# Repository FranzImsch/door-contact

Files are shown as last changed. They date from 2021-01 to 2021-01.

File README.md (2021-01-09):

# "Dr. Sens" Door Contact

## Features
nRF52832-based magnetic door or window contact. It features a <strong>reed switch</strong> that triggers an interrupt pin of the MCU which then sends a message via <strong>Nordic's ESB protocol</strong> to a gateway. The device is powered by a <strong>CR1632 battery cell</strong>.

The board also serves as breakout for i²c and SPI (pin assignment of nrf52-DK) and a pushbutton that is in parallel to the reed switch is populated. This is for development and makes it possible that the board can <strong>be used as a dashbutton</strong>, for example, as well. There is a TX/RX header as well for easy debugging.

## Software
The software was written using the Arduino-Framework. For communication, the [MySensors Library](https://github.com/mysensors) is being used. The MCU goes to sleep until the interrupt is being triggered. After that, it sends a message (along with the battery charge status) to a gateway. When no ACK is received, the message is resend a set number of times.

## Renderings
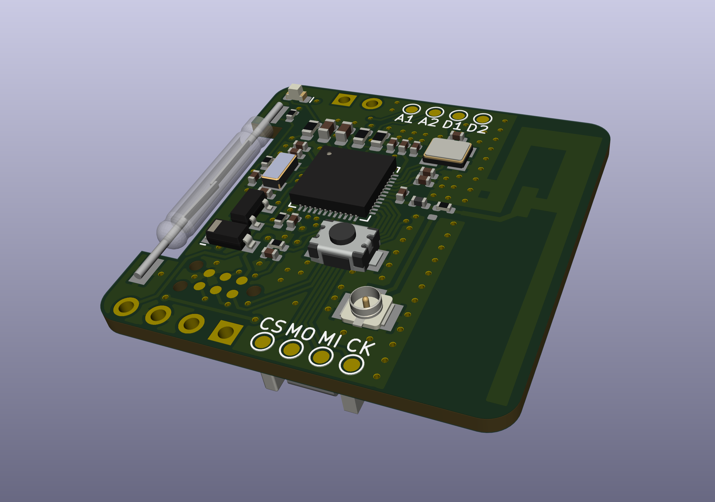
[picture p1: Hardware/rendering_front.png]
Rendering

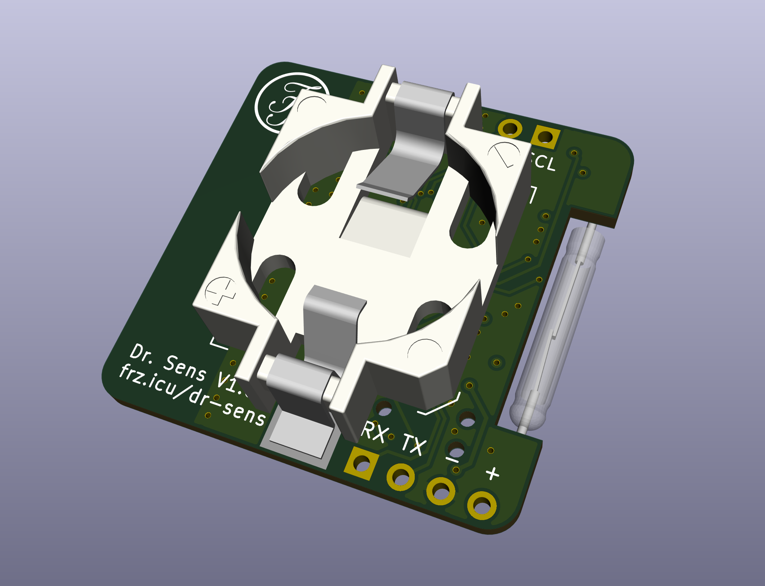
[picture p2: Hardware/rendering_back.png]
Rendering


## Disclaimer
The board is still in development and I do not guarantee any functionality whatsoever. I do not recommend that you use this device to protect your property.

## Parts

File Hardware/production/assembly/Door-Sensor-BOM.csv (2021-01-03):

Comment | Designator | Footprint | LCSC
Antenna_Shield | AE1 | RF_Antenna:Texas_SWRR034C_2.4GHz_Right
Battery_Cell | BT1 | Battery:BatteryHolder_MYOUNG_BS-16-B4AK003
10nF | C1 | Capacitor_SMD:C_0402_1005Metric | C15195
100nF | C4,C5,C10,C15 | Capacitor_SMD:C_0402_1005Metric | C1525
0.8pF | C11 | Capacitor_SMD:C_0402_1005Metric
16pF | C2,C3,C12,C13 | Capacitor_SMD:C_0402_1005Metric | C1548
4.7µF | C6 | Capacitor_SMD:C_0603_1608Metric | C19666
1.0µF | C7 | Capacitor_SMD:C_0603_1608Metric | C15849
100pF | C8 | Capacitor_SMD:C_0402_1005Metric | C1546
DNP | C9,C14 | Capacitor_SMD:C_0402_1005Metric
B5819W | D1 | Diode_SMD:D_SOD-123 | C8598
LED PINK | D2 | LED_SMD:LED_0603_1608Metric
I2C-Conn | J1 | Connector_PinSocket_2.54mm:PinSocket_1x02_P2.54mm_Vertical
PWR-SERIAL-CONN | J2 | Connector_PinHeader_2.54mm:PinHeader_1x04_P2.54mm_Vertical
TC2030 | J3 | Connector:Tag-Connect_TC2030-IDC-NL_2x03_P1.27mm_Vertical
U.FL | J5 | Connector_Coaxial:U.FL_Hirose_U.FL-R-SMT-1_Vertical
3.9nH | L1 | Inductor_SMD:L_0402_1005Metric | C14033
AO3401A | Q1 | Package_TO_SOT_SMD:SOT-23 | C15127
10kΩ | R1 | Resistor_SMD:R_0402_1005Metric | C25744
100kΩ | R2 | Resistor_SMD:R_0402_1005Metric | C25741
4.7MΩ | R3 | Resistor_SMD:R_0603_1608Metric | C23163
10MΩ | R4 | Resistor_SMD:R_0603_1608Metric | C7250
1kΩ | R5 | Resistor_SMD:R_0603_1608Metric | C21190
0Ω | R6 | Resistor_SMD:R_0402_1005Metric | C17168
DNP | R7 | Resistor_SMD:R_0402_1005Metric
1MΩ | R8 | Resistor_SMD:R_0402_1005Metric | C26083
1kΩ | R9 | Resistor_SMD:R_0402_1005Metric | C11702
SW_Reed | SW1 | Button_Switch_SMD:SW_SPST_REED_14.2mm
SW_SPST | SW2 | Button_Switch_SMD:SW_DIP_SPSTx01_Push_TSA343G00-250J2
A1 | TP1 | TestPoint:TestPoint_Pad_D1.0mm
D1 | TP2 | TestPoint:TestPoint_Pad_D1.0mm
D2 | TP3 | TestPoint:TestPoint_Pad_D1.0mm
CS | TP4 | TestPoint:TestPoint_Pad_D1.0mm
MOSI | TP5 | TestPoint:TestPoint_Pad_D1.0mm
MISO | TP6 | TestPoint:TestPoint_Pad_D1.0mm
A2 | TP7 | TestPoint:TestPoint_Pad_D1.0mm
SCK | TP8 | TestPoint:TestPoint_Pad_D1.0mm
nRF52832-QFxx | U1 | Package_DFN_QFN:QFN-48-1EP_6x6mm_P0.4mm_EP4.6x4.6mm | C77540
32.768kHz | Y1 | Crystal:Crystal_SMD_3215-2Pin_3.2x1.5mm | C32346
32MHz | Y2 | Crystal:Crystal_SMD_3225-4Pin_3.2x2.5mm | C9009

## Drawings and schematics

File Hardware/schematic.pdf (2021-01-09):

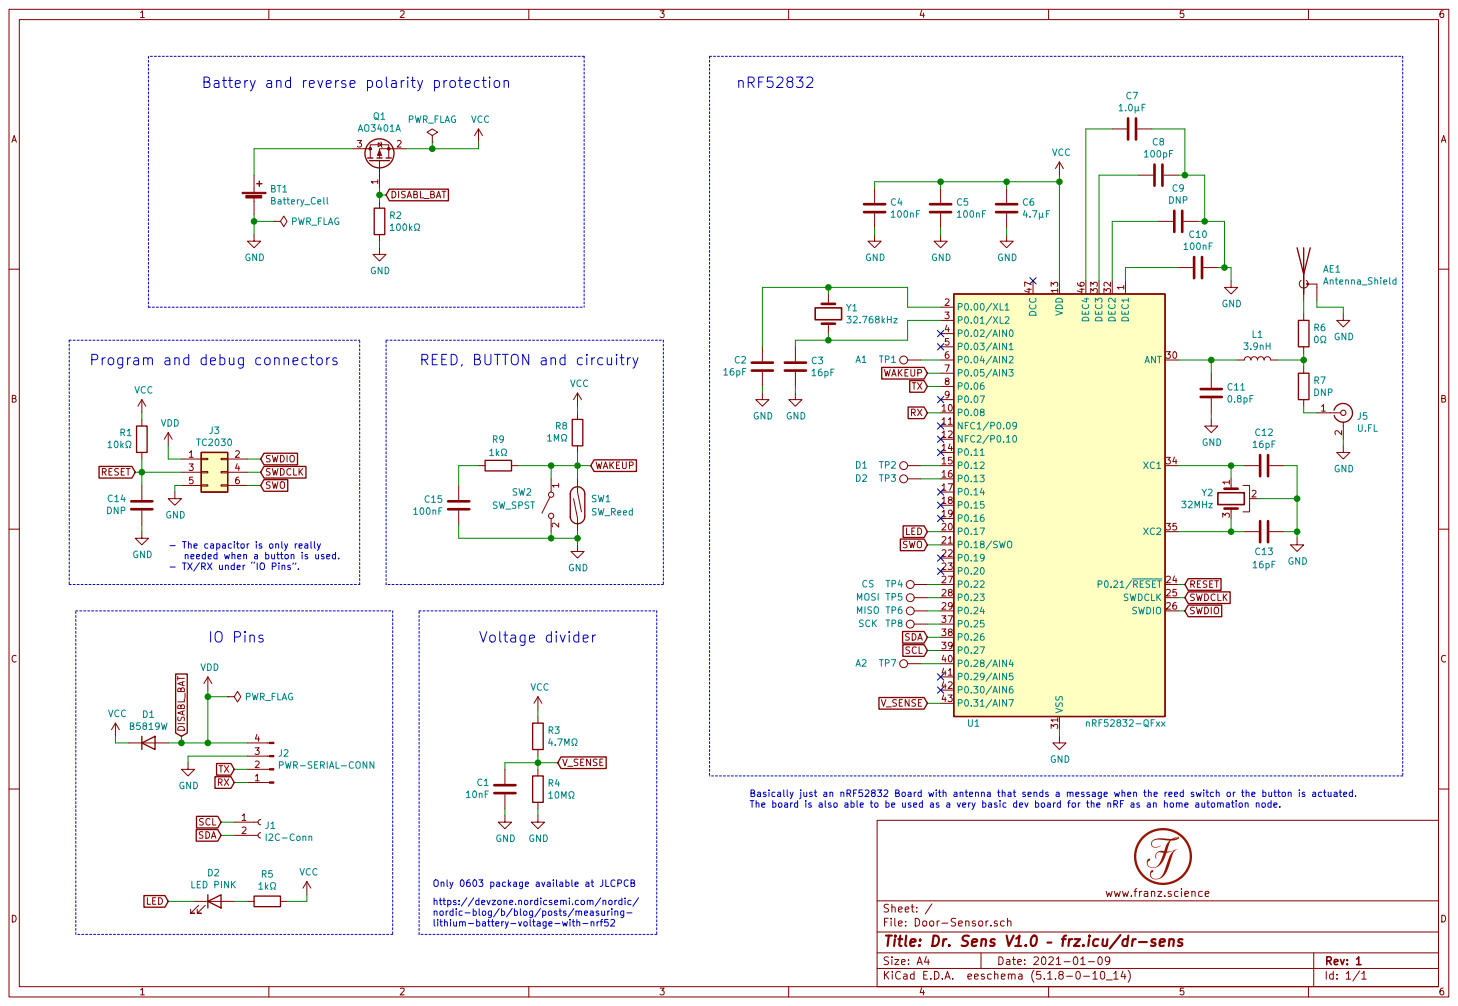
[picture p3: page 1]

1 P0.08 10 NFC1/P0.09 11 NFC2/P0.10 12 VDD 13 P0.11 14 P0.12 15 P0.13 16 P0.14 17 P0.15 18 P0.16 19 P0.00/XL1 2 P0.17 20 P0.18/SWO 21 P0.19 22 P0.20 23 P0.21/RESET 24 SWDCLK 25 SWDIO 26 P0.22 27 P0.23 28 P0.24 29 P0.01/XL2 3 ANT 30 VSS 31 DEC2 32 DEC3 33 XC1 34 XC2 35 P0.25 37 P0.26 38 P0.27 39 P0.02/AIN0 4 P0.28/AIN4 40 P0.29/AIN5 41 P0.30/AIN6 42 P0.31/AIN7 43 DEC4 46 DCC 47 P0.03/AIN1 5 P0.04/AIN2 6 P0.05/AIN3 7 P0.06 8 P0.07 9 U1 nRF52832-QFxx

0 GND GND GND GND

Program and debug connectors

REED, BUTTON and circuitry

- The capacitor is only really

Basically just an nRF52832 Board with antenna that sends a message when the reed switch or the button is actuated.
The board is also able to be used as a very basic dev board for the nRF as an home automation node.

Only 0603 package available at JLCPCB
https://devzone.nordicsemi.com/nordic/
nordic-blog/b/blog/posts/measuring-
lithium-battery-voltage-with-nrf52

Id: 1/1 Title: Dr. Sens V1.0 frz.icu/dr-sens

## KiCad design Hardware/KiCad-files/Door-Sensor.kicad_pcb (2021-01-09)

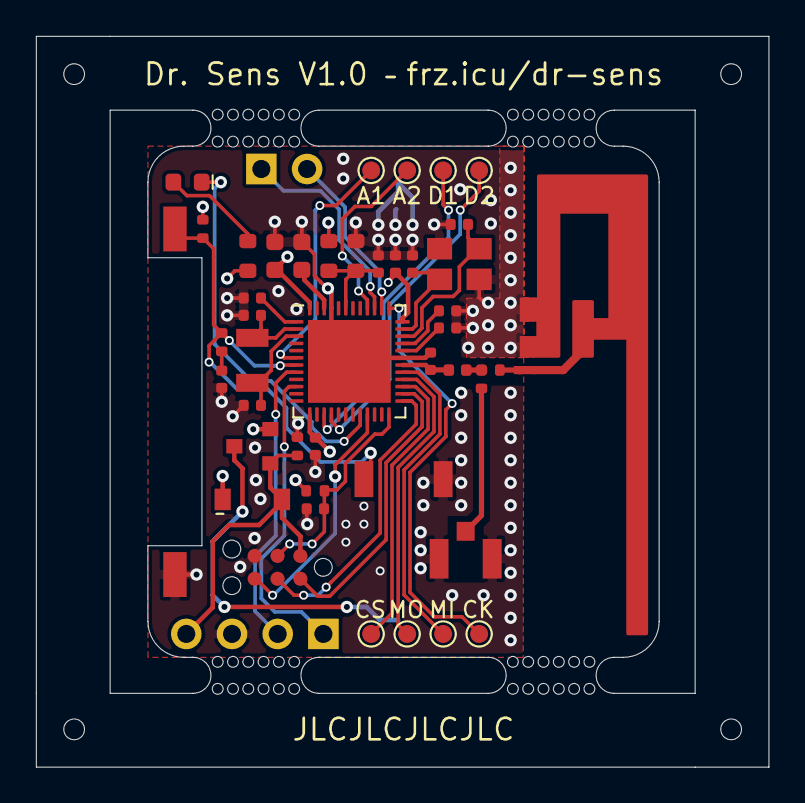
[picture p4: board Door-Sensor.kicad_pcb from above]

Board: 4 copper layers, 40.7 x 40.6 mm, 51 parts (1 on the bottom side), 37 nets.

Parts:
AE1: Antenna_Shield; Texas_SWRR034C_2.4GHz_Right
BT1: Battery_Cell; BatteryHolder_MYOUNG_BS-16-B4AK003
C1: 10nF; C_0402_1005Metric
C2, C3, C12, C13: 16pF; C_0402_1005Metric
C4, C5, C10, C15: 100nF; C_0402_1005Metric
C6: 4.7µF; C_0603_1608Metric
C7: 1.0µF; C_0603_1608Metric
C8: 100pF; C_0402_1005Metric
C9, C14: DNP; C_0402_1005Metric
C11: 0.8pF; C_0402_1005Metric
D1: D; D_SOD-123
D2: LED PINK; LED_0603_1608Metric
J1: I2C-Conn; PinSocket_1x02_P2.54mm_Vertical
J2: PWR-SERIAL-CONN; PinHeader_1x04_P2.54mm_Vertical
J3: TC2030; Tag-Connect_TC2030-IDC-NL_2x03_P1.27mm_Vertical
J5: U.FL; U.FL_Hirose_U.FL-R-SMT-1_Vertical
L1: 3.9nH; L_0402_1005Metric
Q1: AO3401A; SOT-23
R1: 10kΩ; R_0402_1005Metric
R2: 100kΩ; R_0402_1005Metric
R3: 4.7MΩ; R_0603_1608Metric
R4: 10MΩ; R_0603_1608Metric
R5: 1kΩ; R_0603_1608Metric
R6: 0Ω; R_0402_1005Metric
R7: DNP; R_0402_1005Metric
R8: 1MΩ; R_0402_1005Metric
R9: 1kΩ; R_0402_1005Metric
SW1: SW_Reed; SW_SPST_REED_14.2mm
SW2: SW_SPST; SW_DIP_SPSTx01_Push_TSA343G00-250J2
TP1: A1; TestPoint_Pad_D1.0mm
TP2: D1; TestPoint_Pad_D1.0mm
TP3: D2; TestPoint_Pad_D1.0mm
TP4: CS; TestPoint_Pad_D1.0mm
TP5: MOSI; TestPoint_Pad_D1.0mm
TP6: MISO; TestPoint_Pad_D1.0mm
TP7: A2; TestPoint_Pad_D1.0mm
TP8: SCK; TestPoint_Pad_D1.0mm
U1: nRF52832-QFxx; QFN-48-1EP_6x6mm_P0.4mm_EP4.6x4.6mm
Y1: 32.768kHz; Crystal_SMD_3215-2Pin_3.2x1.5mm
Y2: 32MHz; Crystal_SMD_3225-4Pin_3.2x2.5mm
mouse-bite-2mm-slot, mouse-bite-2mm-slot#2, mouse-bite-2mm-slot#3, mouse-bite-2mm-slot#4: VAL**; mouse-bite-2mm-slot

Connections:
DISABL_BAT: D1.2, J2.4, J3.1, Q1.1, R2.1
GND: AE1.2, BT1.2, C1.1, C2.1, C3.2, C4.2, C5.2, C6.2, C7.1, C8.1, C9.1, C10.1, C11.2, C12.1, C13.1, C14.1, C15.2, J2.3, J3.5, J5.2, R2.2, R4.2, SW1.2, SW2.2, U1.31, U1.45, U1.49, Y2.2
LED: D2.1, U1.20
unnamed: AE1.1, R6.1
unnamed: BT1.1, Q1.3
unnamed: C2.2, U1.2, Y1.1
unnamed: C3.1, U1.3, Y1.2
unnamed: C7.2, U1.46
unnamed: C8.2, U1.33
unnamed: C9.2, U1.32
unnamed: C10.2, U1.1
unnamed: C11.1, L1.1, U1.30
unnamed: C12.2, U1.34, Y2.1
unnamed: C13.2, U1.35, Y2.3
unnamed: C15.1, R9.1
unnamed: D2.2, R5.2
unnamed: J5.1, R7.2
unnamed: L1.2, R6.2, R7.1
unnamed: TP1.1, U1.6
unnamed: TP2.1, U1.15
unnamed: TP3.1, U1.16
unnamed: TP4.1, U1.27
unnamed: TP5.1, U1.28
unnamed: TP6.1, U1.29
unnamed: TP7.1, U1.40
unnamed: TP8.1, U1.37
RESET: C14.2, J3.3, R1.1, U1.24
RX: J2.1, U1.10
SCL: J1.1, U1.39
SDA: J1.2, U1.38
SWDCLK: J3.4, U1.25
SWDIO: J3.2, U1.26
SWO: J3.6, U1.21
TX: J2.2, U1.8
VCC: C4.1, C5.1, C6.1, D1.1, Q1.2, R1.2, R3.1, R5.1, R8.2, U1.13, U1.36, U1.48
V_SENSE: C1.2, R3.2, R4.1, U1.43
WAKEUP: R8.1, R9.2, SW1.1, SW2.1, U1.7

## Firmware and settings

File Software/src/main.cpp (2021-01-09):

/************************************
    
    "Dr. Sens" Door Contact (v1.0)
    https://frz.icu/dr-sens

************************************/

#include <Arduino.h>
#include <Arduino_nRF5x_lowPower.h>

/////// MYSENORS SETTINGS ///////
#define MY_DEBUG
#define MY_RADIO_NRF5_ESB
#define CHILD_ID_TRIPPED 1
#define SN "door-dev"
#define SV "1.1"
// #define MY_NODE_ID 193

/////// DEVICE SETTINGS ///////
#define FORCE_SEND_UPDATE_S 0       // Seconds between forced update (0 for off)
#define RESEND_ATTEMPTS 2           // 
#define USE_OB_LED                  // Note: The LED increases power consumption massively.
#define BAT_LVL_INT_S 5             // Minimum time between battery voltage sampling (should be >1s)
#define DOOR_OPEN     HIGH          // When the door is open, the switch is open -> pin pulled high

/////// PIN DEFINITIONS ///////
#define BUTTON_PIN    20            // D20 => P0.05 AIN3
#define LED           6             // D6  => P0.17
#define VOLT_SENSE    A5            // A5  => P0.31 AIN7

/////// VOLTAGE MEASUREMENT ///////
#define ADC_FACTOR        (0.73242188F)   // 3V / 4096
#define RESISTOR_DIVIDER  (678.0F)        // this factor has to be determined for every individual device

#include <MySensors.h>

/////// INTERNALS ///////
MyMessage msg(CHILD_ID_TRIPPED, V_TRIPPED);
bool sentInitialValue = false;
bool resend = false;
byte resendCounter;
long ts;

float batteryCharge(); // moved to bottom of code for cosmetic reasons.

void presentation()
{
  sendSketchInfo(SN, SV);
  present(CHILD_ID_TRIPPED, S_DOOR);
}

void setup()
{
  analogReference(AR_INTERNAL);
  analogReadResolution(12);

  // Turn off internal DC-DC-Converter to save some energies.
  nRF5x_lowPower.disableDCDC();

  pinMode(BUTTON_PIN, INPUT);

#ifdef USE_OB_LED
  pinMode(LED, OUTPUT);
  digitalWrite(LED, HIGH);
#endif
}

void loop()
{
  // For Home Assistant, the first message has to be sent from the loop.
  if (!sentInitialValue)
  {
    send(msg.set("1")); // send dummy value
    sendBatteryLevel(50);
    wait(2000, C_SET, S_DOOR);
    sentInitialValue = true;

    resend = true; // Send actual value after dummy
  }

  if (millis() - ts >= BAT_LVL_INT_S * 1000){
    ts = millis();
    sendBatteryLevel(batteryCharge());
  }

if (!resend){
  Serial.println("sleep");
  sleep(BUTTON_PIN, CHANGE, FORCE_SEND_UPDATE_S * 1000);
}

#ifdef USE_OB_LED
  digitalWrite(LED, LOW);
#endif

if (!send(msg.set(uint32_t(digitalRead(BUTTON_PIN) == DOOR_OPEN ? 1 : 0)))) {
  if (resendCounter <= RESEND_ATTEMPTS){
    Serial.print("resend; counter = ");
    Serial.println(resendCounter);
    resend = true;
    resendCounter++;
  }
  else if (resendCounter > RESEND_ATTEMPTS){
    Serial.println("giving up");
    resend = false;
    resendCounter = 0;
  }
}
else {
  Serial.println("successfully sent");
  resend = false;
  resendCounter = 0;
}

#ifdef USE_OB_LED
  digitalWrite(LED, HIGH);
#endif

  wait(1000);
}

float batteryCharge()
{ // Delay between samples should be > 1sec
  float battery_voltage = (analogRead(VOLT_SENSE) * ADC_FACTOR) / RESISTOR_DIVIDER;
  Serial.println(battery_voltage);

  // Convert voltage to battery level
  // The battery level cannot be calculated that easily (because of the exponential curve
  // of charge vs. voltage), so we have to improvise a bit:

  if (battery_voltage >= 3.20)
  {
    return 100;
  }
  else if (battery_voltage >= 2.30)
  {
    return 95;
  }
  else if (battery_voltage >= 2.20)
  {
    return 90;
  }
  else if (battery_voltage >= 2.15)
  {
    return 85;
  }
  else if (battery_voltage >= 2.10)
  {
    return 80;
  }
  else if (battery_voltage >= 2.05)
  {
    return 75;
  }
  else if (battery_voltage >= 2.00)
  {
    return 70;
  }
  else if (battery_voltage >= 1.99)
  {
    return 60;
  }
  else if (battery_voltage >= 1.98)
  {
    return 50;
  }
  else if (battery_voltage >= 1.97)
  {
    return 40;
  }
  else if (battery_voltage >= 1.96)
  {
    return 30;
  }
  else if (battery_voltage >= 1.95)
  {
    return 10;
  }
  else if (battery_voltage <= 1.95)
  {
    sendBatteryLevel(0);
    wait(2000);
    nRF5x_lowPower.powerMode(POWER_MODE_OFF);
  }
}

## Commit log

2021-01-03 initialising repo
    [Door-Sensor-BOM.csv, Door-Sensor.kicad_pcb, Door-Sensor.sch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]
2021-01-09 added software
    [Door-Sensor-BOM.csv, Door-Sensor-no-edge-rails.kicad_pcb, Door-Sensor.kicad_pcb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]
